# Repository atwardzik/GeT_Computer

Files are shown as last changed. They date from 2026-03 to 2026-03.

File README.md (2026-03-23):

# GeT Computer

A custom-designed single-board computer built with RP2354B MCU. This project serves as a hardware platform for my experimental [operating system](https://github.com/atwardzik/os_kernel). In its form it was inspired by the original Raspberry Pi SBC. However, it features an MCU that is much more managable in terms of low level development, as it is provided with comprehensive [datasheet](https://pip-assets.raspberrypi.com/categories/1214-rp2350/documents/RP-008373-DS-2-rp2350-datasheet.pdf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) covering all details. Additionally, the board includes hardware interfaces (VGA, PS2, microSD) specifically selected for their simplicity in driver implementation. The board also features Ethernet chip by WIZNet and slot for soldering Raspberry Pi Radio Module.

This repository contains the **hardware design files** (KiCad schematics, PCB layout, BOM).

## What's in This Repository

- **KiCad Project Files** (`.kicad_pcb`, `.kicad_sch`, `.kicad_pro`)
- **Bill of Materials (BOM)**
- **Gerber Files** for manufacturing

## Visual Overview

### Schematic
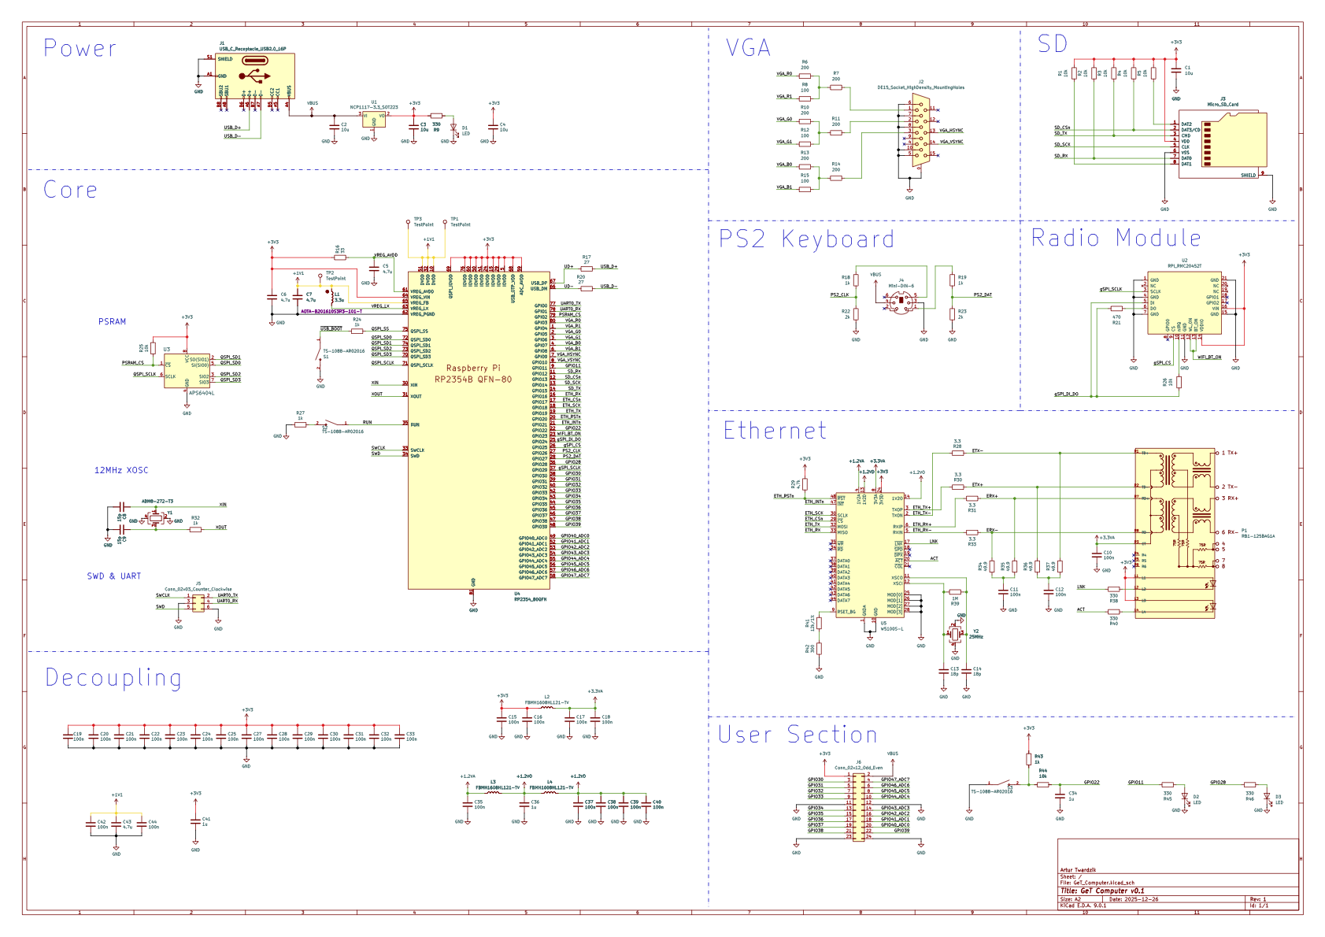
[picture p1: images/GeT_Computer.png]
Schematic


### KiCad Design View
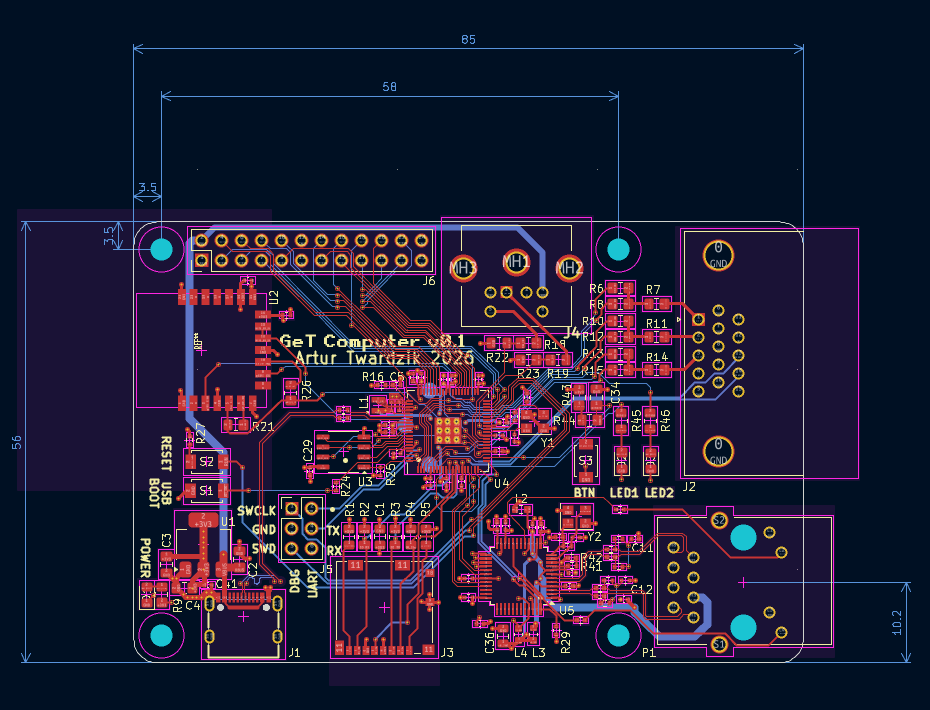
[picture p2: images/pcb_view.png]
PCB Kicad View


### Physical PCB
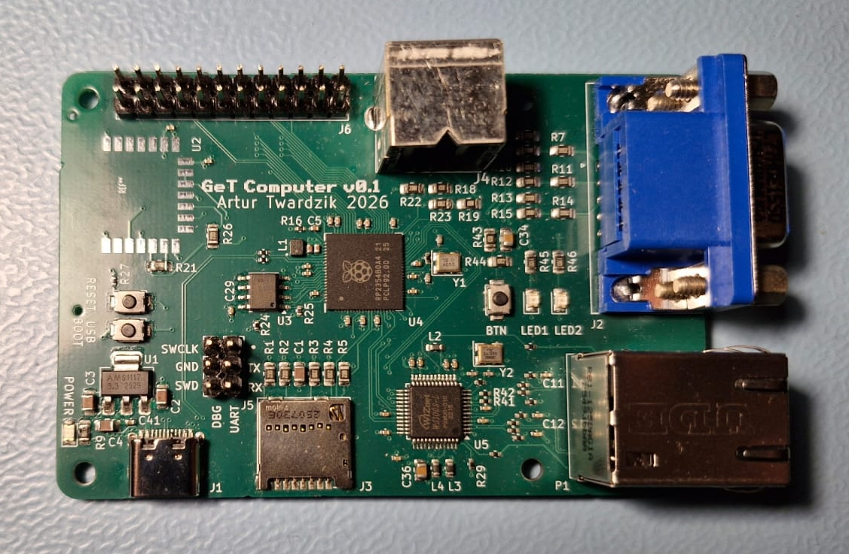
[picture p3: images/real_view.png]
Real PCB


## Hardware Specifications

| Feature | Specification |
|---|---|
| Processor | RP2354B |
| RAM | 520KB internal SRAM + 8MB external PSRAM |
| Non-volatile storage | microSD Card |
| Ethernet | WIZnet W5100S |
| WiFi and Bluetooth | Raspberry Pi Radio Module 2 (RM2) |
| IO | VGA@640x480 and PS2 keyboard |
| Power Input | 5V @ 1A |
| Dimensions | 85mm x 56mm x 17mm |
| Stackup | 4-layer with power and ground planes |

## Viewing the Design
1. Install [KiCad](https://www.kicad.org/) (version [9.0+])
2. Open `GeT_Computer.kicad_pro`
3. Explore schematics and PCB layout

## Software

This hardware was designed specifically for the [GeT OS](https://github.com/atwardzik/os_kernel). The OS repo contains:
- Kernel code
- Drivers for peripherals.
- Build instructions

## Contributing
Although the project is already manufactured, feel free to open any issues regarding problems you may have found.

## License
CC BY-NC-SA 4.0

Copyright (c) 2026, Artur Twardzik

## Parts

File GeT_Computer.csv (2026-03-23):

Reference | Value | Footprint | Datasheet | Qty | DNP | Exclude from BOM | Exclude from Board
C1,C2,C3,C4 | 10u | Capacitor_SMD:C_0805_2012Metric_Pad1.18x1.45mm_HandSolder | ~ | 4
C5,C43 | 4.7u | Capacitor_SMD:C_0402_1005Metric | ~ | 2
C6,C7 | 4.7u | RP2350_80QFN_minimal:C_0402_1005Metric_small_pads | ~ | 2
C8,C9 | 15p | Capacitor_SMD:C_0402_1005Metric | ~ | 2
C10,C11,C12,C15,C16,C17,C18,C19,C20,C21,C22,C23,C24,C25,C27,C28,C29,C30,C31,C32,C33,C35,C37,C38,C39,C40,C42,C44 | 100n | Capacitor_SMD:C_0402_1005Metric | ~ | 28
C13,C14 | 18p | Capacitor_SMD:C_0402_1005Metric | ~ | 2
C34 | 1u | Capacitor_SMD:C_0805_2012Metric_Pad1.18x1.45mm_HandSolder | ~ | 1
C36 | 1u | Capacitor_SMD:C_0805_2012Metric | ~ | 1
C41 | 1u | Capacitor_SMD:C_0402_1005Metric | ~ | 1
D1,D2,D3 | LED | LED_SMD:LED_0805_2012Metric_Pad1.15x1.40mm_HandSolder | ~ | 3
J1 | USB_C_Receptacle_USB2.0_16P | Connector_USB:USB-C_SMD-TYPE-C-31-M-12 | https://www.usb.org/sites/default/files/documents/usb_type-c.zip | 1
J2 | DE15_Socket_HighDensity_MountingHoles | Connector_Dsub:DSUB-15-HD_Socket_Horizontal_P2.29x2.54mm_EdgePinOffset8.35mm_Housed_MountingHolesOffset10.89mm | ~ | 1
J3 | Micro_SD_Card | Connector_Card:microSD_HC_Molex_104031-0811 | https://www.we-online.com/components/products/datasheet/693072010801.pdf | 1
J4 | Mini-DIN-6 | Connector:mini-din-6 | http://service.powerdynamics.com/ec/Catalog17/Section%2011.pdf | 1
J5 | Conn_02x03_Counter_Clockwise | Connector_PinHeader_2.54mm:PinHeader_2x03_P2.54mm_Vertical | ~ | 1
J6 | Conn_02x12_Odd_Even | Connector_PinHeader_2.54mm:PinHeader_2x12_P2.54mm_Vertical | ~ | 1
L1 | 3.3u | RP2350_80QFN_minimal:L_pol_2016 | ~ | 1
L2,L3,L4 | FBMH1608HL121-TV | Inductor_SMD:L_0603_1608Metric | ~ | 3
P1 | RB1-125BAG1A | GeT_Footprints_Library:WIZNET_RB1-125BAG1A |  | 1
R1,R2,R3,R4,R5,R26,R44 | 10k | Resistor_SMD:R_0805_2012Metric_Pad1.20x1.40mm_HandSolder | ~ | 7
R6,R7,R10,R11,R13,R14 | 200 | Resistor_SMD:R_0805_2012Metric_Pad1.20x1.40mm_HandSolder | ~ | 6
R8,R12,R15 | 100 | Resistor_SMD:R_0805_2012Metric_Pad1.20x1.40mm_HandSolder | ~ | 3
R9,R45,R46 | 330 | Resistor_SMD:R_0805_2012Metric_Pad1.20x1.40mm_HandSolder | ~ | 3
R16 | 33 | Resistor_SMD:R_0402_1005Metric | ~ | 1
R17,R20 | 27 | Resistor_SMD:R_0402_1005Metric | ~ | 2
R18,R19,R43 | 1k | Resistor_SMD:R_0805_2012Metric_Pad1.20x1.40mm_HandSolder | ~ | 3
R21 | 470 | Resistor_SMD:R_0805_2012Metric_Pad1.20x1.40mm_HandSolder | ~ | 1
R22,R23 | 2k | Resistor_SMD:R_0805_2012Metric_Pad1.20x1.40mm_HandSolder | ~ | 2
R24,R27,R32 | 1k | Resistor_SMD:R_0402_1005Metric | ~ | 3
R25 | 10k | Resistor_SMD:R_0402_1005Metric | ~ | 1
R28,R30,R31,R33 | 3.3 | Resistor_SMD:R_0402_1005Metric | ~ | 4
R29 | 4.7k | Resistor_SMD:R_0402_1005Metric | ~ | 1
R34,R35,R36,R37 | 49.9 | Resistor_SMD:R_0402_1005Metric | ~ | 4
R38,R40 | 330 | Resistor_SMD:R_0402_1005Metric | ~ | 2
R39 | 1M | Resistor_SMD:R_0402_1005Metric | ~ | 1
R41 | 12k/1% | Resistor_SMD:R_0402_1005Metric | ~ | 1
R42 | 300 | Resistor_SMD:R_0402_1005Metric | ~ | 1
S1,S2,S3 | TS-1088-AR02016 | GeT_Footprints_Library:SW_TS-1088-AR02016 |  | 3
TP1,TP2,TP3 | TestPoint | TestPoint:TestPoint_Pad_D2.0mm | ~ | 3
U1 | NCP1117-3.3_SOT223 | Package_TO_SOT_SMD:SOT-223-3_TabPin2 | http://www.onsemi.com/pub_link/Collateral/NCP1117-D.PDF | 1
U2 | RPI_RMC20452T | GeT_Library:rpi_rmc20452t |  | 1
U3 | APS6404L | Package_SO:SOP-8_3.9x4.9mm_P1.27mm | APS6404L-3SQR-SN | 1
U4 | RP2354_80QFN | GeT_Footprints_Library:RP2354-QFN-80-1EP_10x10_P0.4mm_EP3.4x3.4mm_ThermalVias_1 |  | 1
U5 | W5100S-L | Package_QFP:LQFP-48_7x7mm_P0.5mm | https://docs.wiznet.io/img/products/w5100s/w5100s-ds-v128e.pdf | 1
Y1 | ABM8-272-T3 | Crystal:Crystal_SMD_3225-4Pin_3.2x2.5mm | ~ | 1
Y2 | 25MHz | Crystal:Crystal_SMD_3225-4Pin_3.2x2.5mm | ~ | 1

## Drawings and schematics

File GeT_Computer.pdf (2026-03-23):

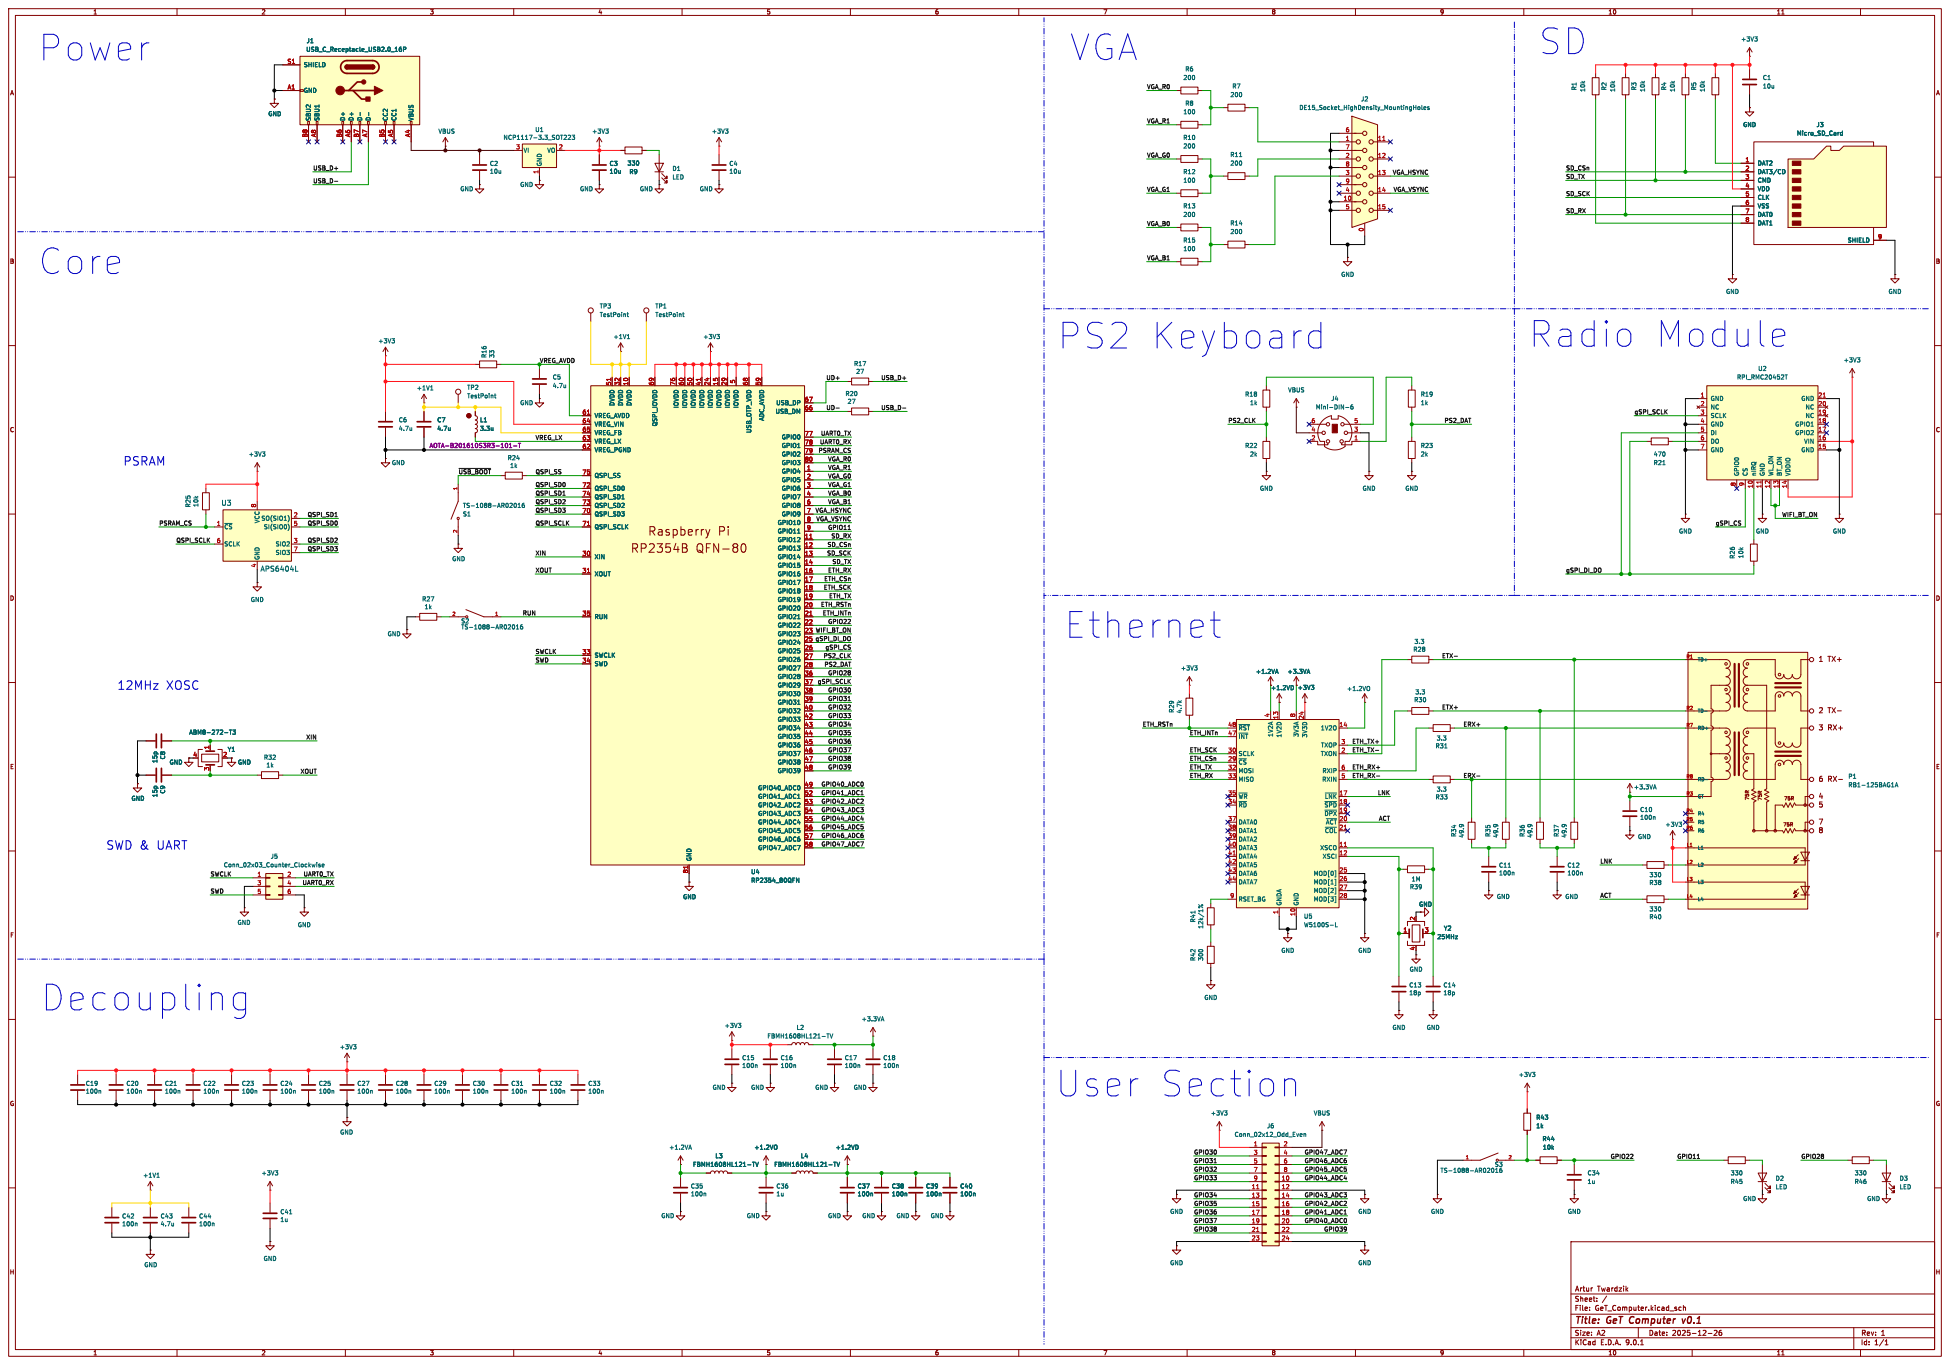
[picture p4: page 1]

9 nIRQ 10 GND 11 WL_ON 12 BT_ON 13 VDDIO 14 GND

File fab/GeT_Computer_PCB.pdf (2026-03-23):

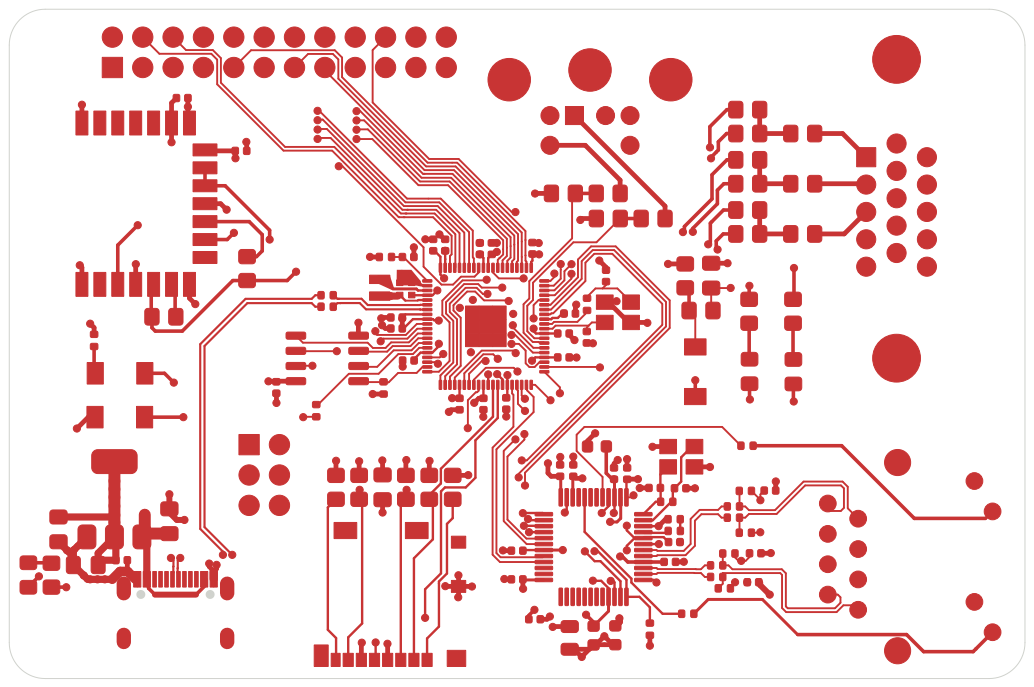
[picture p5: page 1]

Id: 1/6 Title: GeT Computer PCB

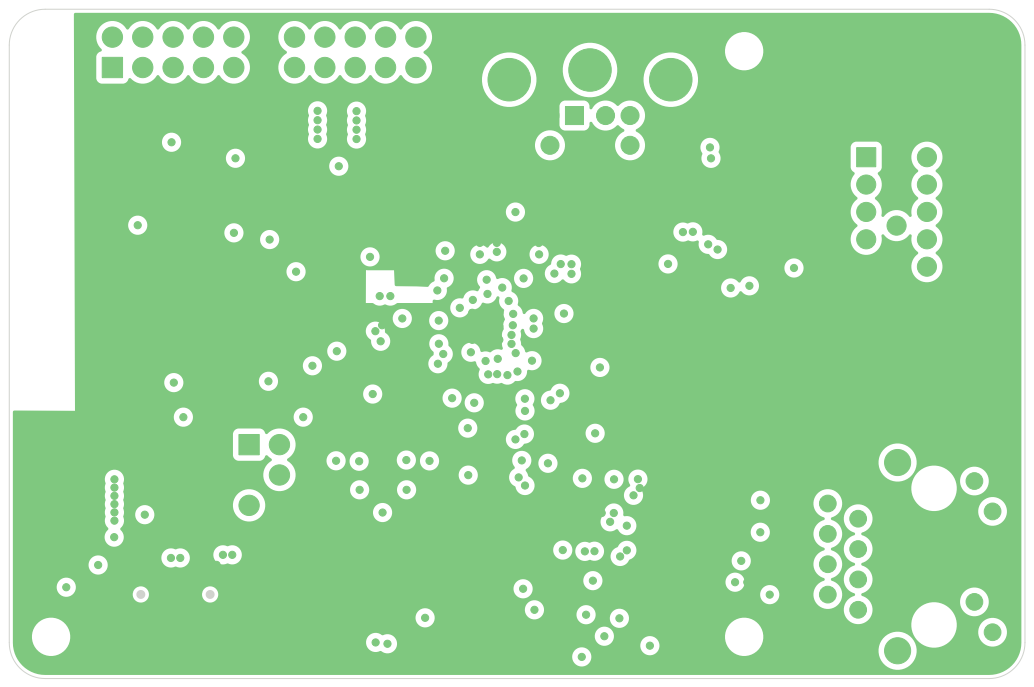
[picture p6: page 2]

Id: 2/6 Title: GeT Computer PCB

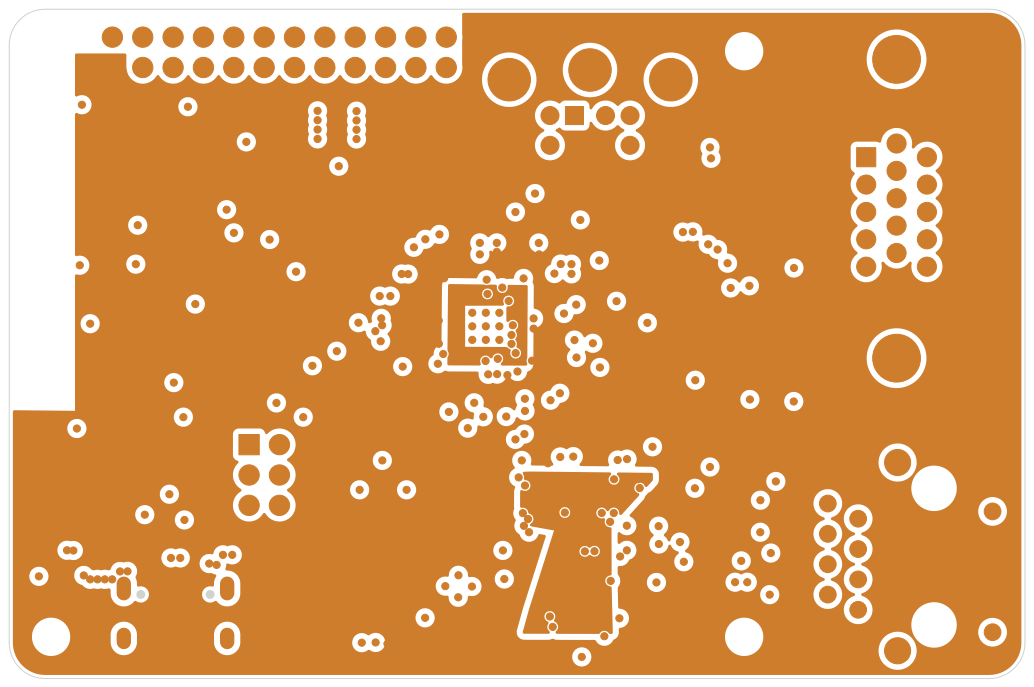
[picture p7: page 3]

Id: 3/6 Title: GeT Computer PCB

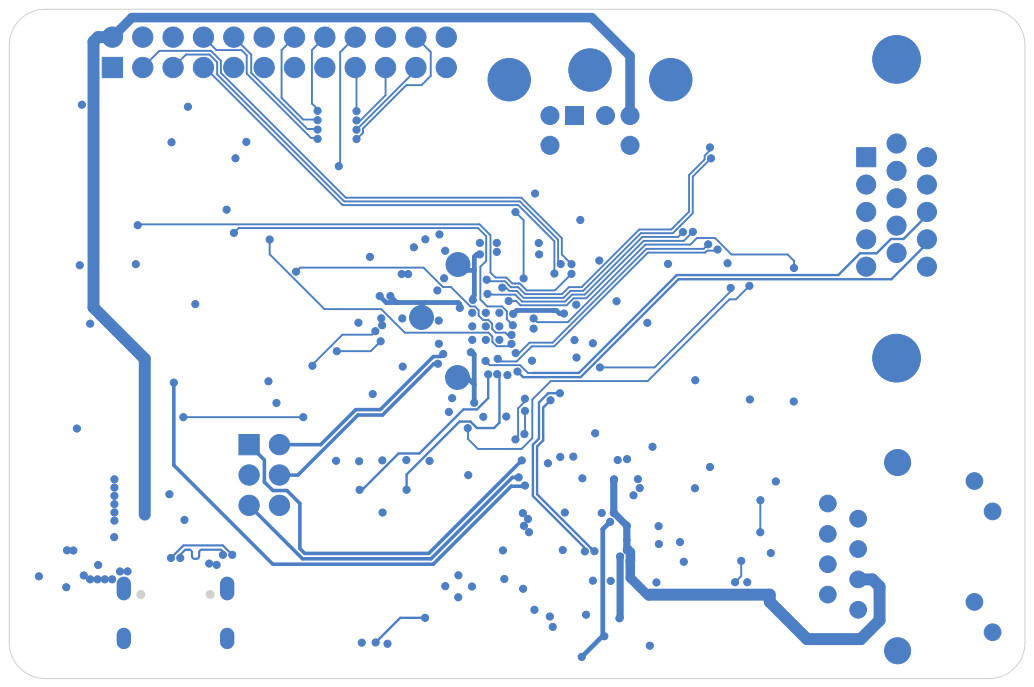
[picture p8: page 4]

Id: 4/6 Title: GeT Computer PCB

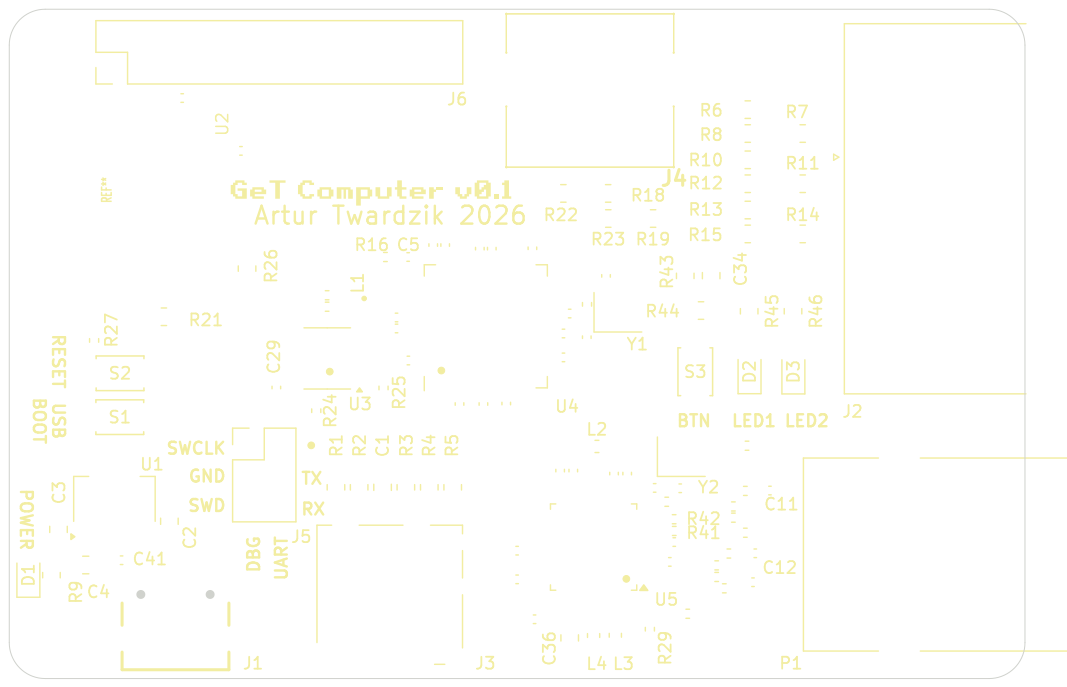
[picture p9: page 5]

Id: 5/6 Title: GeT Computer PCB

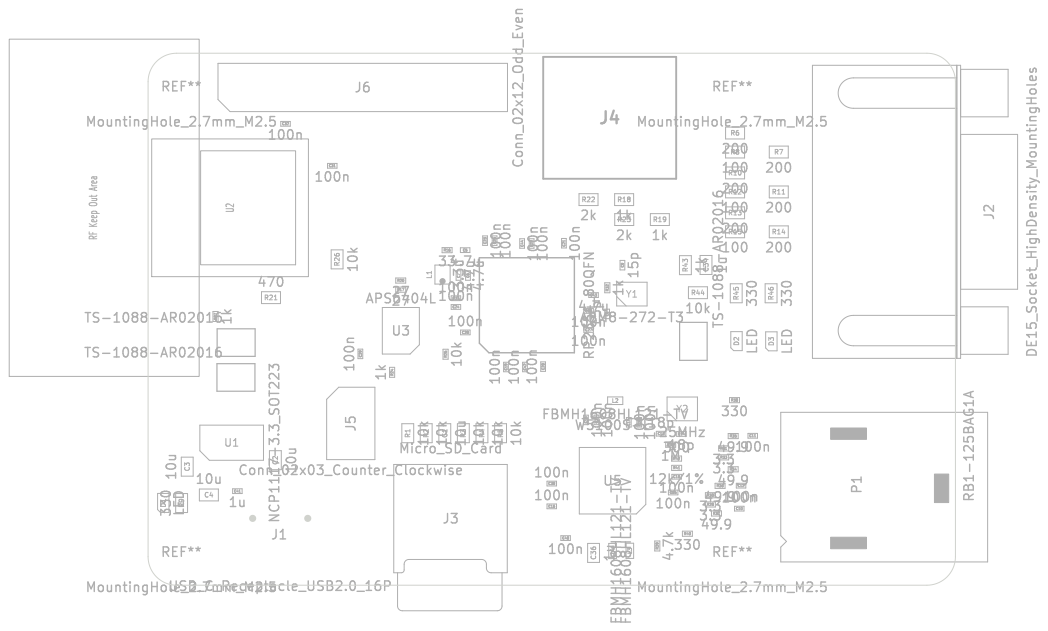
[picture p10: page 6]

Id: 6/6 Title: GeT Computer PCB

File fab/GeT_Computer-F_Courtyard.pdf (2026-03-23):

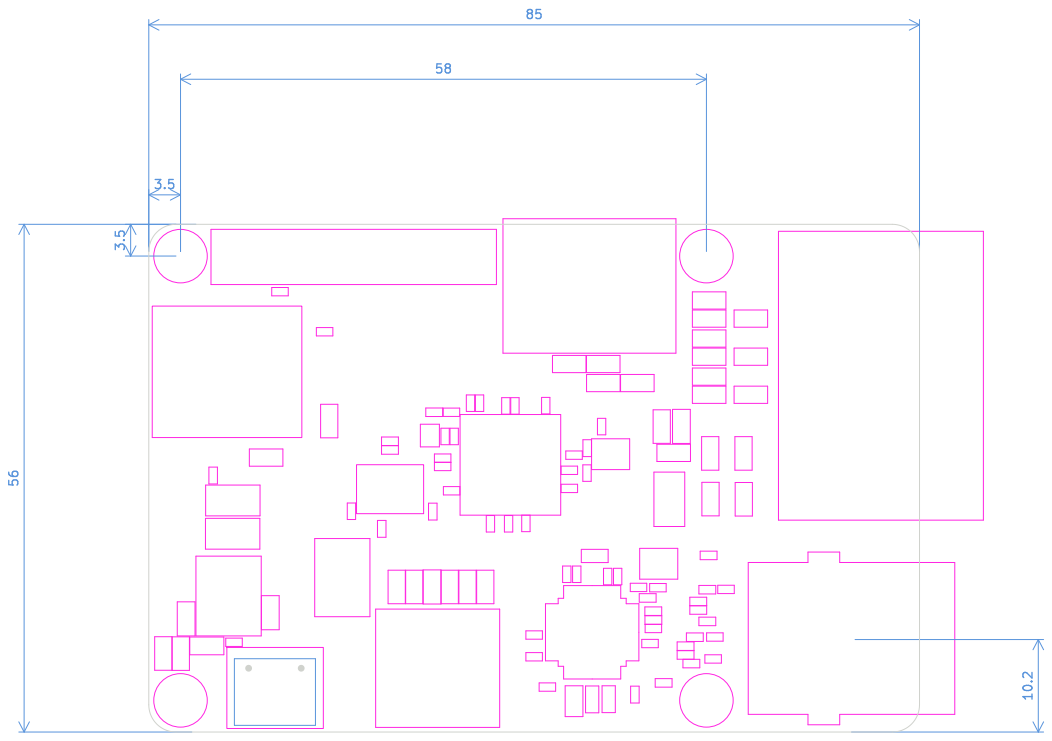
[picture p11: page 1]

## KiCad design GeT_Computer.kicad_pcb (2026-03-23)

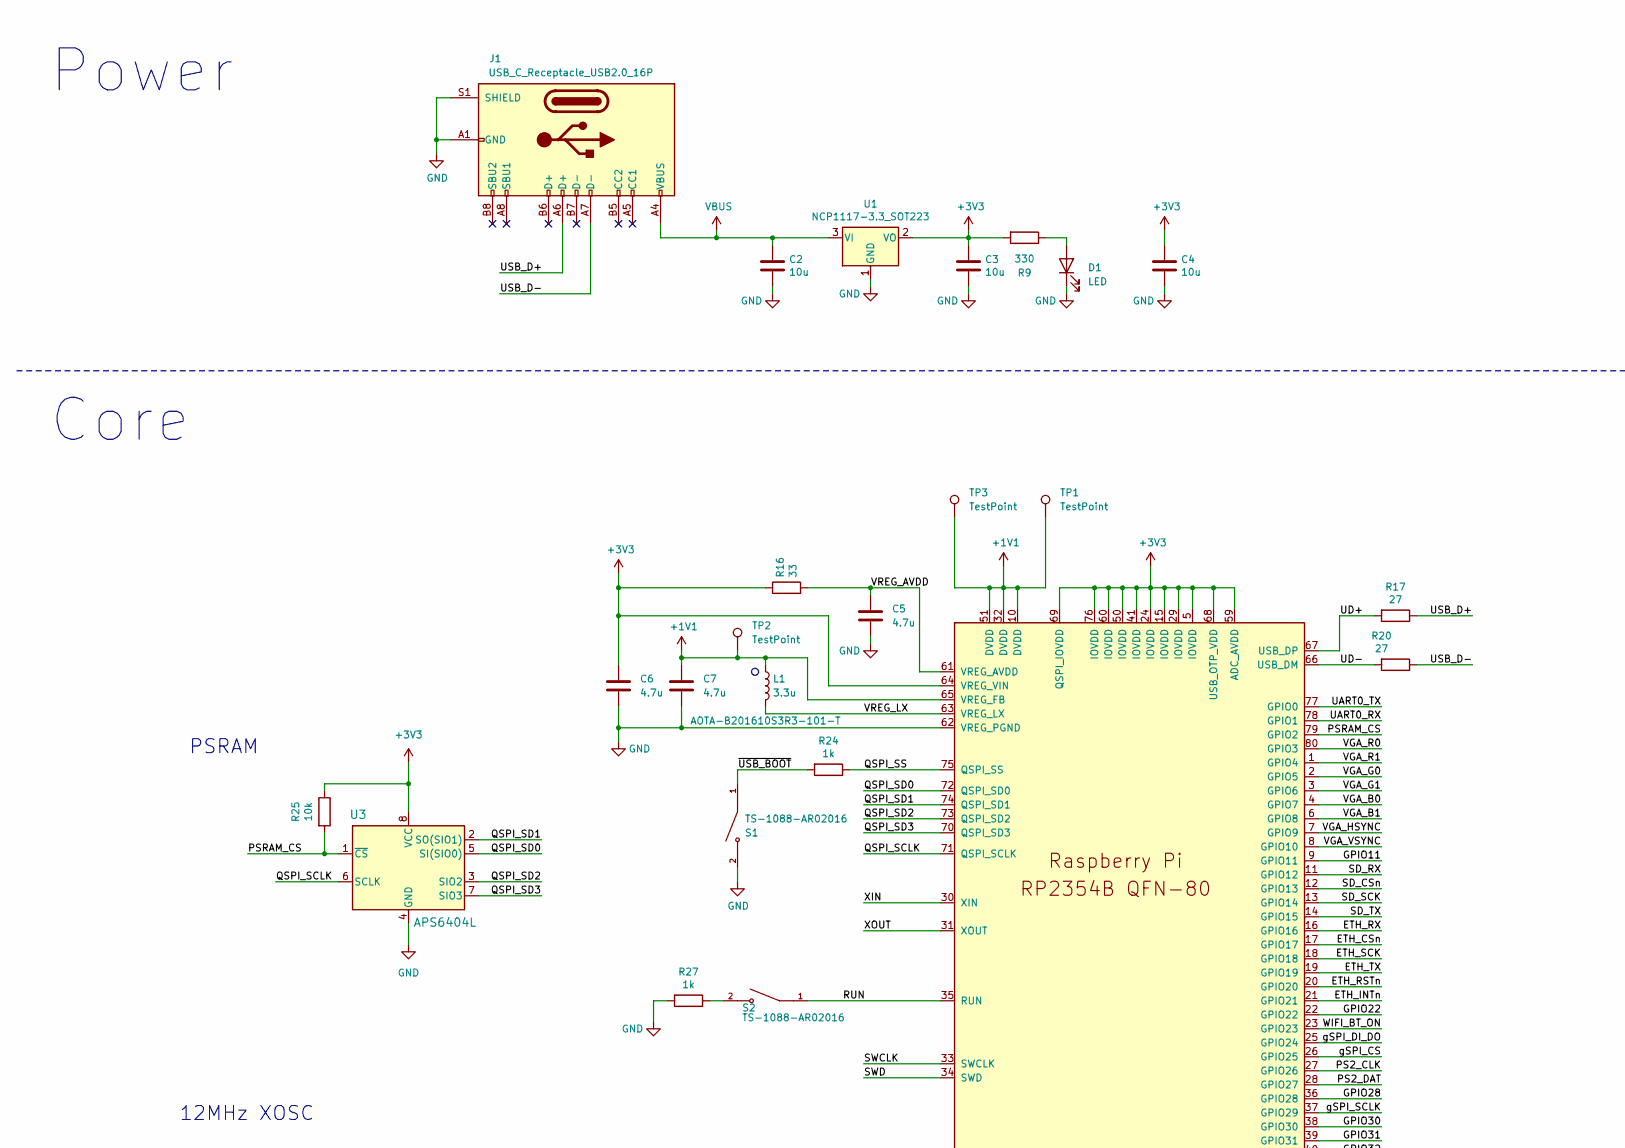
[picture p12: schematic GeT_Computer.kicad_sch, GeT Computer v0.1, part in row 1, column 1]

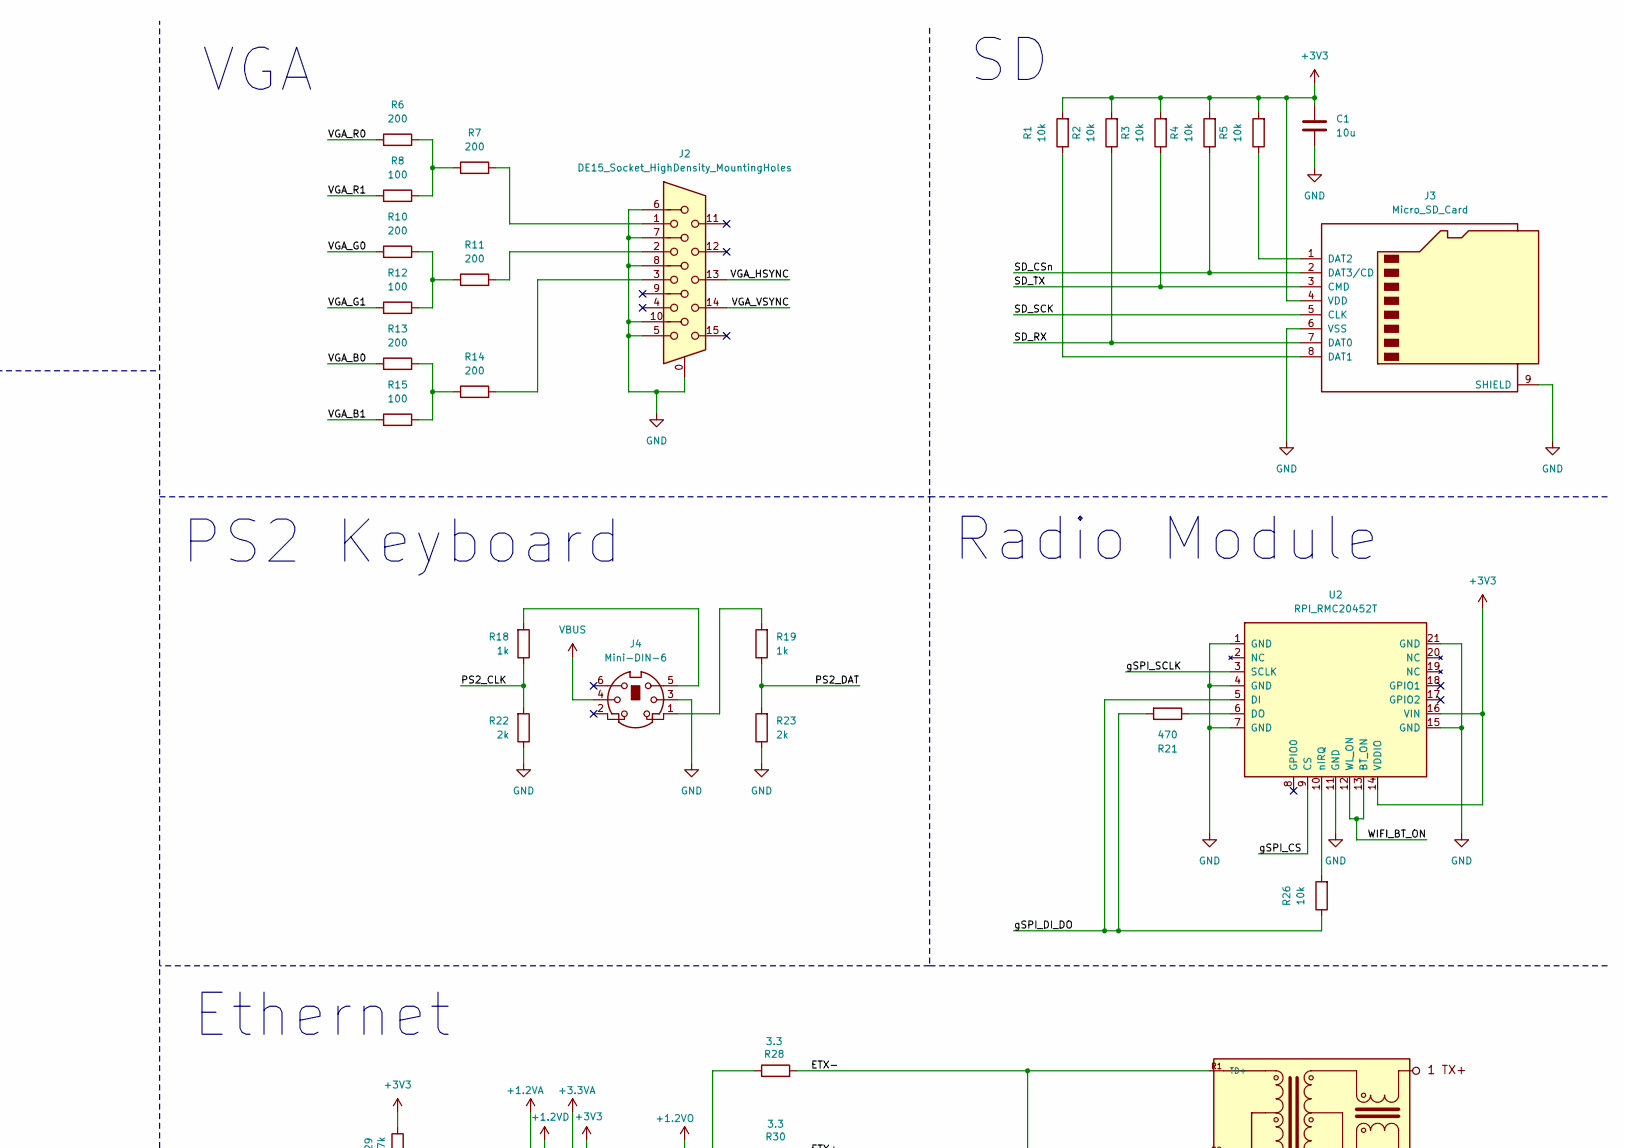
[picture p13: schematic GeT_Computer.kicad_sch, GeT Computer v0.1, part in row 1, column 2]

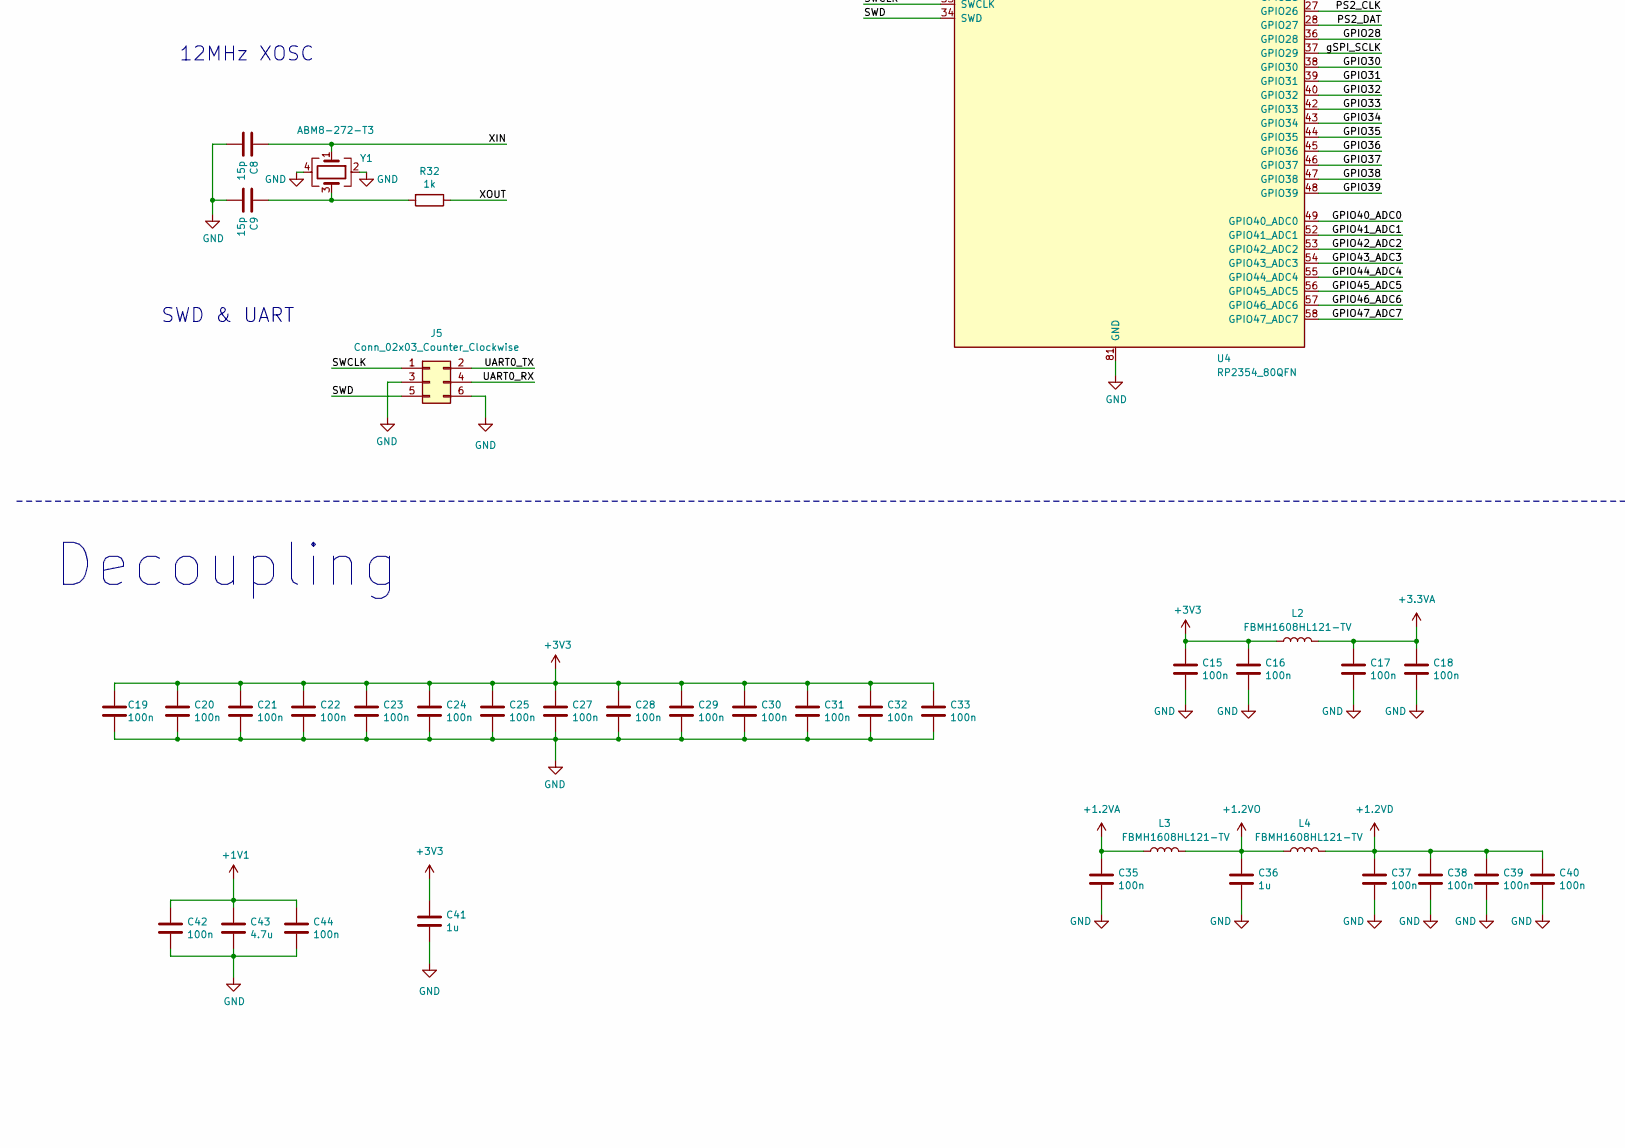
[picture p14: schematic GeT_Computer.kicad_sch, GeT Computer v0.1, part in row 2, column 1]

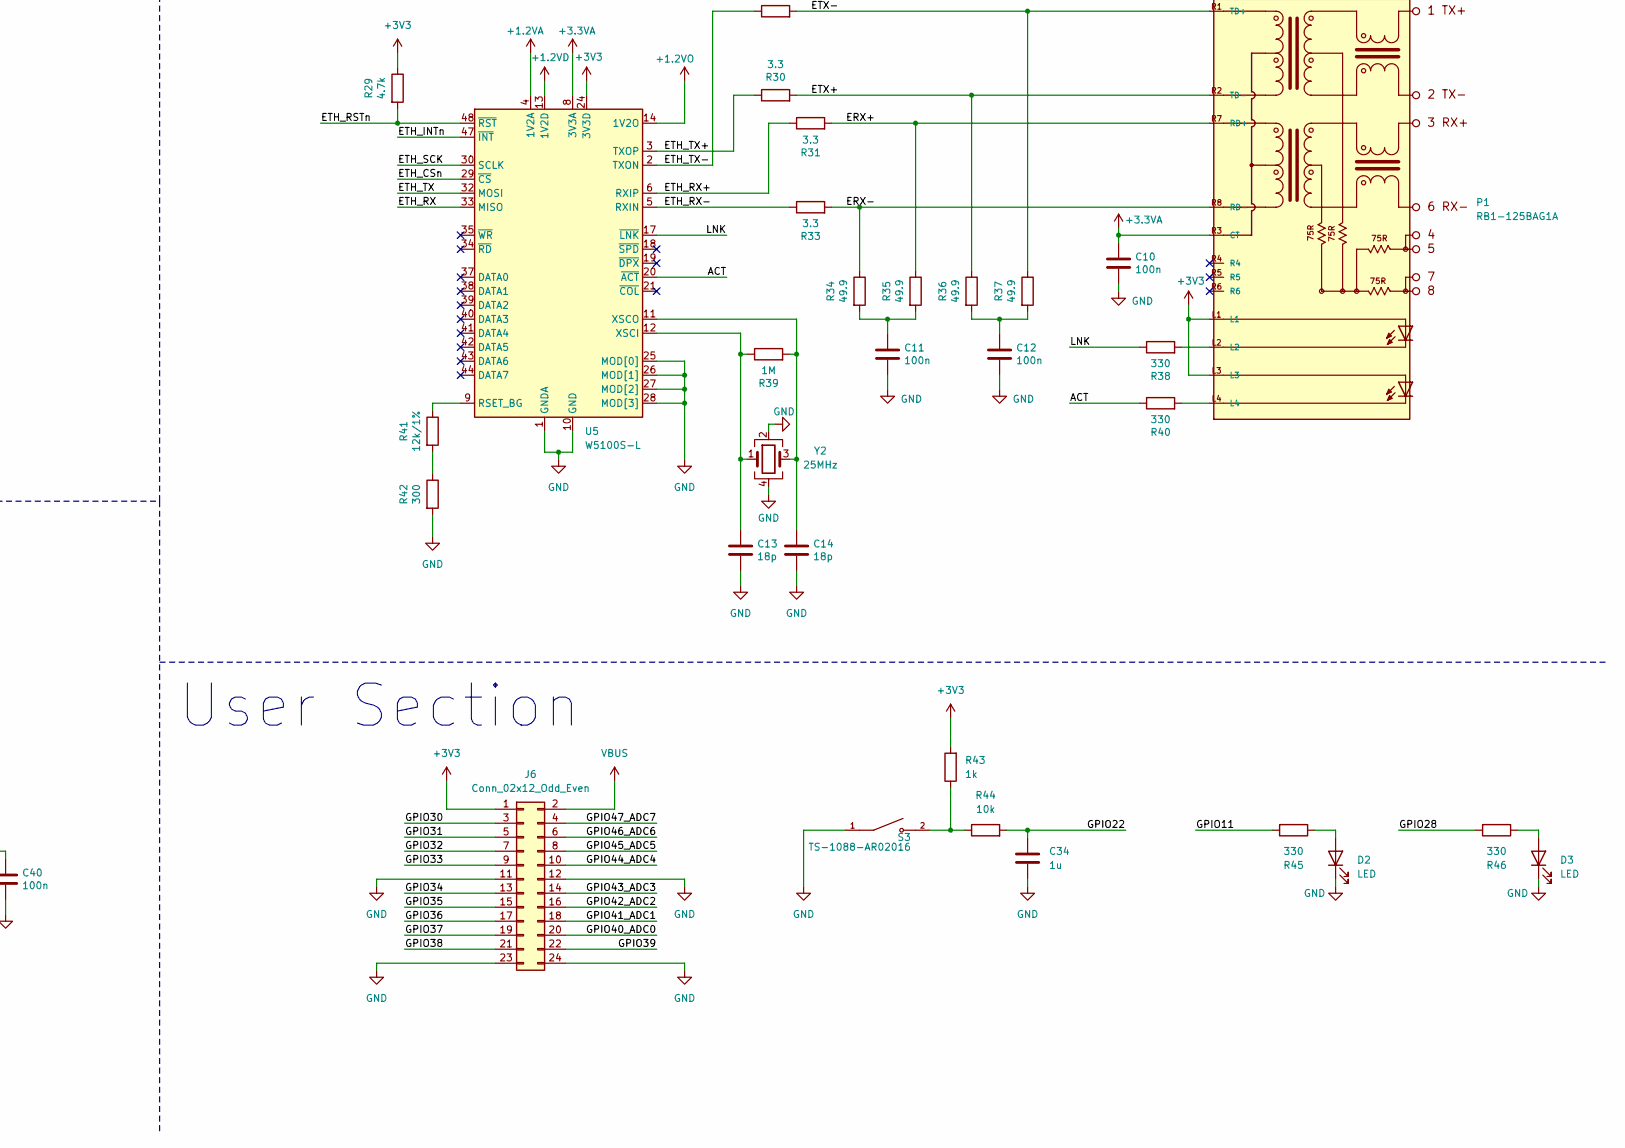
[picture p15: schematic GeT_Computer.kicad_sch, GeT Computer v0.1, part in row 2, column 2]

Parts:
C1, C2, C3, C4: 10u; C_0805_2012Metric_Pad1.18x1.45mm_HandSolder
C5, C43: 4.7u; C_0402_1005Metric
C6, C7: 4.7u; C_0402_1005Metric_small_pads
C8, C9: 15p; C_0402_1005Metric
C10, C11, C12, C15, C16, C17, C18, C19, C20, C21, C22, C23, C24, C25, C27, C28, C29, C30, C31, C32, C33, C35, C37, C38, C39, C40, C42, C44: 100n; C_0402_1005Metric
C13, C14: 18p; C_0402_1005Metric
C34: 1u; C_0805_2012Metric_Pad1.18x1.45mm_HandSolder
C36: 1u; C_0805_2012Metric
C41: 1u; C_0402_1005Metric
D1, D2, D3: LED; LED_0805_2012Metric_Pad1.15x1.40mm_HandSolder
J1: USB_C_Receptacle_USB2.0_16P; USB-C_SMD-TYPE-C-31-M-12
J2: DE15_Socket_HighDensity_MountingHoles; DSUB-15-HD_Socket_Horizontal_P2.29x2.54mm_EdgePinOffset8.35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
J3: Micro_SD_Card; microSD_HC_Molex_104031-0811
J4: Mini-DIN-6; mini-din-6
J5: Conn_02x03_Counter_Clockwise; PinHeader_2x03_P2.54mm_Vertical
J6: Conn_02x12_Odd_Even; PinHeader_2x12_P2.54mm_Vertical
L1: 3.3u; L_pol_2016
L2, L3, L4: FBMH1608HL121-TV; L_0603_1608Metric
P1: RB1-125BAG1A; WIZNET_RB1-125BAG1A
R1, R2, R3, R4, R5, R26, R44: 10k; R_0805_2012Metric_Pad1.20x1.40mm_HandSolder
R6, R7, R10, R11, R13, R14: 200; R_0805_2012Metric_Pad1.20x1.40mm_HandSolder
R8, R12, R15: 100; R_0805_2012Metric_Pad1.20x1.40mm_HandSolder
R9, R45, R46: 330; R_0805_2012Metric_Pad1.20x1.40mm_HandSolder
R16: 33; R_0402_1005Metric
R17, R20: 27; R_0402_1005Metric
R18, R19, R43: 1k; R_0805_2012Metric_Pad1.20x1.40mm_HandSolder
R21: 470; R_0805_2012Metric_Pad1.20x1.40mm_HandSolder
R22, R23: 2k; R_0805_2012Metric_Pad1.20x1.40mm_HandSolder
R24, R27, R32: 1k; R_0402_1005Metric
R25: 10k; R_0402_1005Metric
R28, R30, R31, R33: 3.3; R_0402_1005Metric
R29: 4.7k; R_0402_1005Metric
R34, R35, R36, R37: 49.9; R_0402_1005Metric
R38, R40: 330; R_0402_1005Metric
R39: 1M; R_0402_1005Metric
R41: 12k/1%; R_0402_1005Metric
R42: 300; R_0402_1005Metric
S1, S2, S3: TS-1088-AR02016; SW_TS-1088-AR02016; PARTREV N/A
TP1, TP2, TP3: TestPoint; TestPoint_Pad_D2.0mm
U1: NCP1117-3.3_SOT223; SOT-223-3_TabPin2
U2: RPI_RMC20452T; rpi_rmc20452t
U3: APS6404L; SOP-8_3.9x4.9mm_P1.27mm
U4: RP2354_80QFN; RP2354-QFN-80-1EP_10x10_P0.4mm_EP3.4x3.4mm_ThermalVias_1
U5: W5100S-L; LQFP-48_7x7mm_P0.5mm
Y1: ABM8-272-T3; Crystal_SMD_3225-4Pin_3.2x2.5mm
Y2: 25MHz; Crystal_SMD_3225-4Pin_3.2x2.5mm

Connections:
+1.2VA: C35.1, L3.1, U5.4 (1V2A)
+1.2VD: C37.1, C38.1, C39.1, C40.1, L4.2, U5.13 (1V2D), U5.22 (1V2D), U5.31 (1V2D), U5.45 (1V2D)
+1.2VO: C36.1, L3.2, L4.1, U5.14 (1V2O)
+1V1: C7.1, C42.1, C43.1, C44.1, L1.1, TP1.1, TP2.1, TP3.1, U4.10 (DVDD), U4.32 (DVDD), U4.51 (DVDD), U4.65 (VREG_FB)
+3.3VA: C10.1, C17.1, C18.1, L2.2, P1.R3 (CT), U5.8 (3V3A), U5.15 (3V3A)
+3V3: C1.1, C3.1, C4.1, C6.1, C15.1, C16.1, C19.1, C20.1, C21.1, C22.1, C23.1, C24.1, C25.1, C27.1, C28.1, C29.1, C30.1, C31.1, C32.1, C33.1, C41.1, J3.4 (VDD), J6.1, L2.1, P1.L1, P1.L3, R1.2, R2.2, R3.2, R4.2, R5.2, R9.2, R16.1, R25.1, R29.1, R43.2, U1.2 (VO), U2.14 (VDDIO), U2.16 (VIN), U3.8 (VCC), U4.5 (IOVDD), U4.15 (IOVDD), U4.24 (IOVDD), U4.29 (IOVDD), U4.41 (IOVDD), U4.50 (IOVDD), U4.59 (ADC_AVDD), U4.60 (IOVDD), U4.64 (VREG_VIN), U4.68 (USB_OTP_VDD), U4.69 (QSPI_IOVDD), U4.76 (IOVDD), U5.24 (3V3D), U5.36 (3V3D)
/ACT: R40.1, U5.20 (~ACT)
/ERX+: P1.R7 (RD+), R31.2, R35.1
/ERX-: P1.R8 (RD-), R33.2, R34.1
/ETH_CSn: U4.17 (GPIO17), U5.29 (~CS)
/ETH_INTn: U4.21 (GPIO21), U5.47 (~INT)
/ETH_RSTn: R29.2, U4.20 (GPIO20), U5.48 (~RST)
/ETH_RX: U4.16 (GPIO16), U5.33 (MISO)
/ETH_RX+: R31.1, U5.6 (RXIP)
/ETH_RX-: R33.1, U5.5 (RXIN)
/ETH_SCK: U4.18 (GPIO18), U5.30 (SCLK)
/ETH_TX: U4.19 (GPIO19), U5.32 (MOSI)
/ETH_TX+: R30.1, U5.3 (TXOP)
/ETH_TX-: R28.1, U5.2 (TXON)
/ETX+: P1.R2 (TD-), R30.2, R36.1
/ETX-: P1.R1 (TD+), R28.2, R37.1
/GPIO11: R45.2, U4.9 (GPIO11)
/GPIO22: C34.1, R44.2, U4.22 (GPIO22)
/GPIO28: R46.2, U4.36 (GPIO28)
/GPIO30: J6.3, U4.38 (GPIO30)
/GPIO31: J6.5, U4.39 (GPIO31)
/GPIO32: J6.7, U4.40 (GPIO32)
/GPIO33: J6.9, U4.42 (GPIO33)
/GPIO34: J6.13, U4.43 (GPIO34)
/GPIO35: J6.15, U4.44 (GPIO35)
/GPIO36: J6.17, U4.45 (GPIO36)
/GPIO37: J6.19, U4.46 (GPIO37)
/GPIO38: J6.21, U4.47 (GPIO38)
/GPIO39: J6.22, U4.48 (GPIO39)
/GPIO40_ADC0: J6.20, U4.49 (GPIO40_ADC0)
/GPIO41_ADC1: J6.18, U4.52 (GPIO41_ADC1)
/GPIO42_ADC2: J6.16, U4.53 (GPIO42_ADC2)
/GPIO43_ADC3: J6.14, U4.54 (GPIO43_ADC3)
/GPIO44_ADC4: J6.10, U4.55 (GPIO44_ADC4)
/GPIO45_ADC5: J6.8, U4.56 (GPIO45_ADC5)
/GPIO46_ADC6: J6.6, U4.57 (GPIO46_ADC6)
/GPIO47_ADC7: J6.4, U4.58 (GPIO47_ADC7)
/LNK: R38.1, U5.17 (~LNK)
/PS2_CLK: R18.1, R22.2, U4.27 (GPIO26)
/PS2_DAT: R19.1, R23.2, U4.28 (GPIO27)
/PSRAM_CS: R25.2, U3.1 (~CS), U4.79 (GPIO2)
/QSPI_SCLK: U3.6 (SCLK), U4.71 (QSPI_SCLK)
/QSPI_SD0: U3.5 (SI(SIO0)), U4.72 (QSPI_SD0)
/QSPI_SD1: U3.2 (SO(SIO1)), U4.74 (QSPI_SD1)
/QSPI_SD2: U3.3 (SIO2), U4.73 (QSPI_SD2)
/QSPI_SD3: U3.7 (SIO3), U4.70 (QSPI_SD3)
/QSPI_SS: R24.1, U4.75 (QSPI_SS)
/RUN: S2.1, U4.35 (RUN)
/SD_CSn: J3.2 (DAT3/CD), R4.1, U4.12 (GPIO13)
/SD_RX: J3.7 (DAT0), R2.1, U4.11 (GPIO12)
/SD_SCK: J3.5 (CLK), U4.13 (GPIO14)
/SD_TX: J3.3 (CMD), R3.1, U4.14 (GPIO15)
/SWCLK: J5.1, U4.33 (SWCLK)
/SWD: J5.5, U4.34 (SWD)
/UART0_RX: J5.4, U4.78 (GPIO1)
/UART0_TX: J5.2, U4.77 (GPIO0)
/UD+: R17.2, U4.67 (USB_DP)
/UD-: R20.2, U4.66 (USB_DM)
/USB_D+: J1.A6 (D+), R17.1
/USB_D-: J1.A7 (D-), R20.1
/VGA_B0: R13.1, U4.4 (GPIO7)
/VGA_B1: R15.1, U4.6 (GPIO8)
/VGA_G0: R10.1, U4.2 (GPIO5)
/VGA_G1: R12.1, U4.3 (GPIO6)
/VGA_HSYNC: J2.13, U4.7 (GPIO9)
/VGA_R0: R6.1, U4.80 (GPIO3)
/VGA_R1: R8.1, U4.1 (GPIO4)
/VGA_VSYNC: J2.14, U4.8 (GPIO10)
/VREG_AVDD: C5.1, R16.2, U4.61 (VREG_AVDD)
/VREG_LX: L1.2, U4.63 (VREG_LX)
/WIFI_BT_ON: U2.12 (WL_ON), U2.13 (BT_ON), U4.23 (GPIO23)
/XIN: C8.1, U4.30 (XIN), Y1.1
/XOUT: R32.1, U4.31 (XOUT)
/gSPI_CS: U2.9 (CS), U4.26 (GPIO25)
/gSPI_DI_DO: R21.2, R26.1, U2.5 (DI), U4.25 (GPIO24)
/gSPI_SCLK: U2.3 (SCLK), U4.37 (GPIO29)
/~USB_BOOT: R24.2, S1.1
GND: C1.2, C2.2, C3.2, C4.2, C5.2, C6.2, C7.2, C8.2, C9.2, C10.2, C11.2, C12.2, C13.2, C14.2, C15.2, C16.2, C17.2, C18.2, C19.2, C20.2, C21.2, C22.2, C23.2, C24.2, C25.2, C27.2, C28.2, C29.2, C30.2, C31.2, C32.2, C33.2, C34.2, C35.2, C36.2, C37.2, C38.2, C39.2, C40.2, C41.2, C42.2, C43.2, C44.2, D1.1 (K), D2.1 (K), D3.1 (K), J1.A1 (GND), J1.A12 (GND), J1.B1 (GND), J1.B12 (GND), J1.S1 (SHIELD), J2.0, J2.5, J2.6, J2.7, J2.8, J2.10, J3.6 (VSS), J3.9 (SHIELD), J4.3, J5.3, J5.6, J6.11, J6.12, J6.23, J6.24, R22.1, R23.1, R27.2, R42.2, S1.2, S3.1, U1.1 (GND), U2.1 (GND), U2.4 (GND), U2.7 (GND), U2.11 (GND), U2.15 (GND), U2.21 (GND), U3.4 (GND), U4.62 (VREG_PGND), U4.81 (GND), U5.1 (GNDA), U5.7 (GNDA), U5.10 (GND), U5.16 (GNDA), U5.23 (GND), U5.25 (MOD[0]), U5.26 (MOD[1]), U5.27 (MOD[2]), U5.28 (MOD[3]), U5.46 (GND), Y1.2, Y1.4, Y2.2, Y2.4
unnamed: C9.1, R32.2, Y1.3
unnamed: C11.1, R34.2, R35.2
unnamed: C12.1, R36.2, R37.2
unnamed: D1.2 (A), R9.1
unnamed: D2.2 (A), R45.1
unnamed: D3.2 (A), R46.1
unnamed: J2.1, R7.2
unnamed: J2.2, R11.2
unnamed: J2.3, R14.2
unnamed: J3.8 (DAT1), R1.1
unnamed: J3.1 (DAT2), R5.1
unnamed: J4.1, R19.2
unnamed: J4.5, R18.2
unnamed: P1.L2, R38.2
unnamed: P1.L4, R40.2
unnamed: R6.2, R7.1, R8.2
unnamed: R10.2, R11.1, R12.2
unnamed: R13.2, R14.1, R15.2
unnamed: R27.1, S2.2
unnamed: R41.2, R42.1
unnamed: R43.1, R44.1, S3.2
unnamed: R21.1, U2.6 (DO)
unnamed: R26.2, U2.10 (nIRQ)
unnamed: R41.1, U5.9 (RSET_BG)
unnamed: C13.1, R39.1, U5.12 (XSCI), Y2.1
unnamed: C14.1, R39.2, U5.11 (XSCO), Y2.3
VBUS: C2.1, J1.A4 (VBUS), J1.A9 (VBUS), J1.B4 (VBUS), J1.B9 (VBUS), J4.4, J6.2, U1.3 (VI)

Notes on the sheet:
VGA
12MHz XOSC
SWD & UART
Power
PS2 Keyboard
Core
Ethernet
User Section
Decoupling
Radio Module
PSRAM

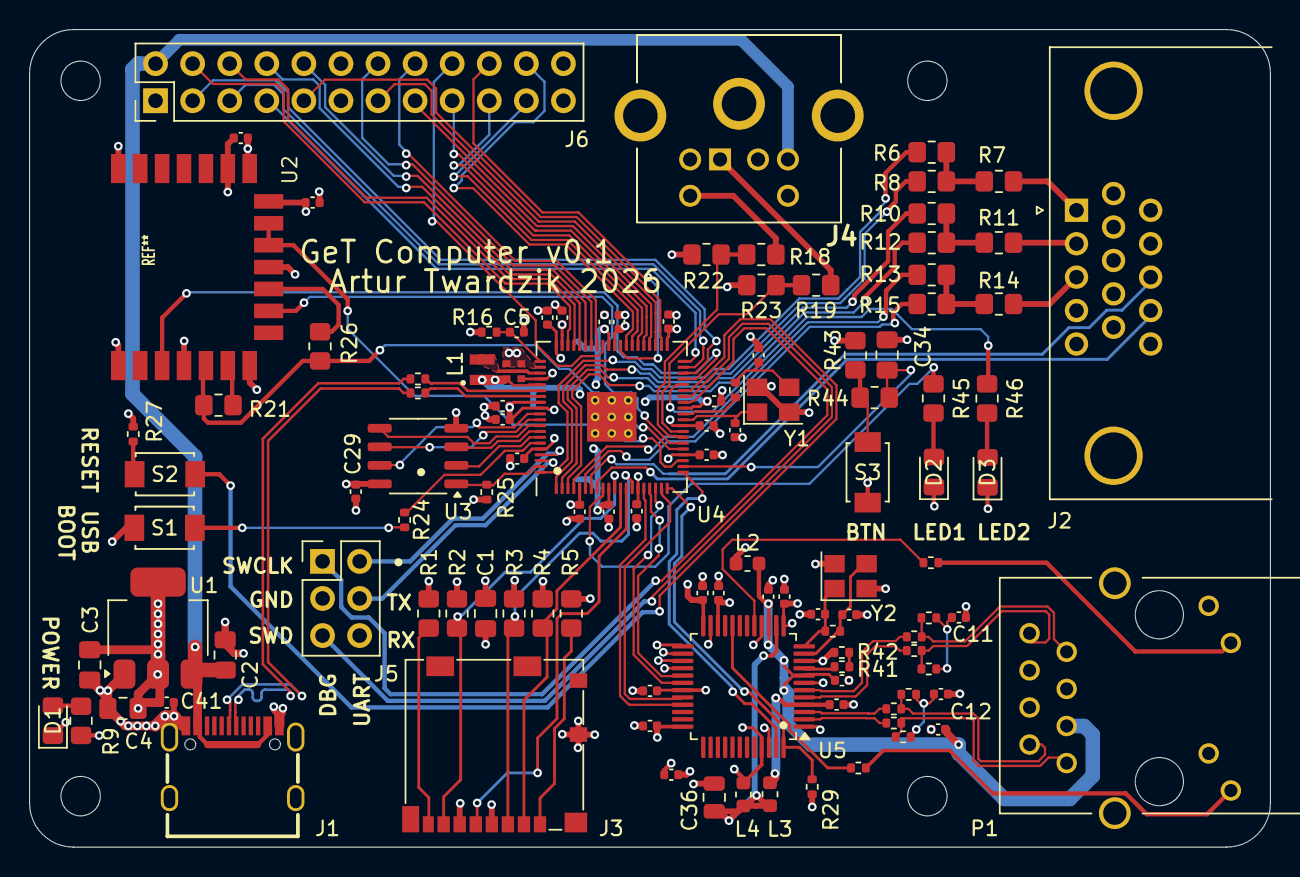
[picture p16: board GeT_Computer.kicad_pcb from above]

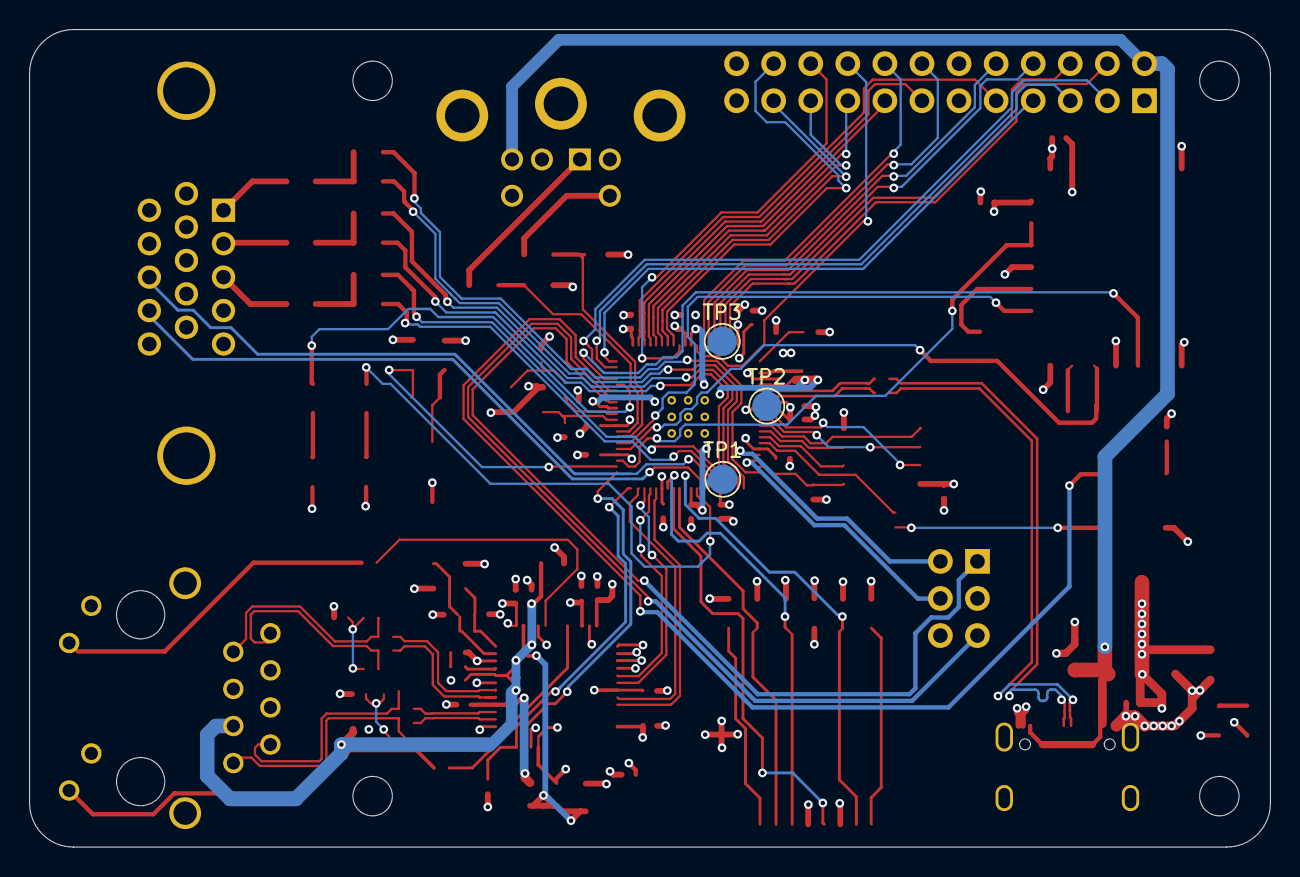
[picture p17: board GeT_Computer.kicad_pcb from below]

Board: 4 copper layers, 85.0 x 56.0 mm, 116 parts (3 on the bottom side), 110 nets.

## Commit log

2026-01-05 Update Schematic
2026-03-23 Add final version of the project that was printed and assembled
    [GeT_Computer.csv, GeT_Computer.kicad_pcb, GeT_Computer.kicad_sch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]
2026-03-23 Add fabrication output
    [GeT_Computer-B_Cu.gbr, GeT_Computer-B_Fab.gbr, GeT_Computer-B_Mask.gbr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]
2026-03-23 Add schematic to README
